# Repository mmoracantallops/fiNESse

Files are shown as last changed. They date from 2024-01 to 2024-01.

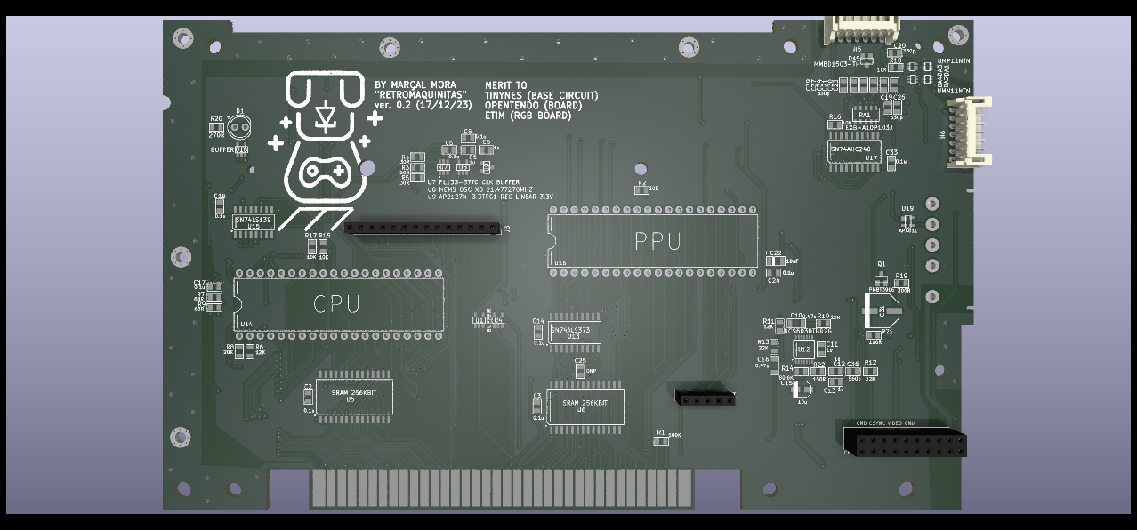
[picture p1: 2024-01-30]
MAIN_BOARD/FINESSE.png

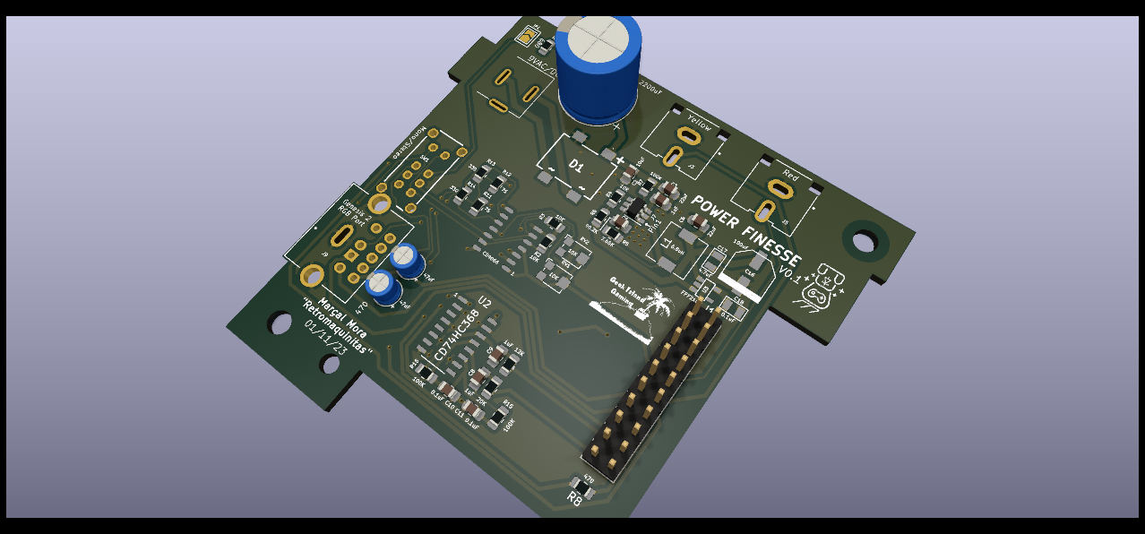
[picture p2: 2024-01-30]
POWER_BOARD/NES_POWER_FINESSE.png

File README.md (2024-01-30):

# fiNESse
Final Integrated NES Special Edition: Integration and adaptation of the best NES projects (TinyNES, NESRGB, OpenTendo and Power Module Redesign) in a single modern unit.

TinyNES: https://www.crowdsupply.com/tall-dog-electronics/tinynes

TinyNES: https://github.com/loglow/TinyNES

OpenTendo: https://github.com/Redherring32/OpenTendo

NESRGB: https://etim.net.au/nesrgb/

MerlinShaw's Power Modules: https://github.com/ShawMerlin/NES-Power-Module-Redesign

# Features (and limitations)
- Only NTSC (once you go 60Hz, there is no turning back), so RP2A03 / RP2C02, as the clock generator uses the NTSC frequency.
- Main board:
    - Similar features as the TinyNES project, although some features have been changed, simplified or adapted to my project (for instance, no USB or TRRS or clone compatibility here).
    - Modern ICs. All components are new and available.
    - Programmable clock generator (SIT2001BC-S2-33N-21.477270).
    - Reset supervisor (APX811).
    - Sockets to place the NESRGB Board wirelessly. Also taking external composite and audio from it.
    - Composite video generation and audio amplifier (internal).
    - Expansion audio connected.
- Power board:
    - Mini Din9 connector (MD/genesis 2 cable).
    - Rectifier (all polarities allowed).
    - Power load switch which provide full protection to systems and loads which may encounter large current conditions.
    - 5V step-down regulator.
    - Pseudo-stereo (separated channels CPU1 and CPU2). Mono is also mixed with both (adjustable on how much) so expansion audio is also mixed if desired.
    - Stereo audio is amplified with the same buffer as the original design.
    - Three-way switch (CVBS - mono, CSync - stereo, Csync - mono).
    - Much better routing and cleaner ground plane - although still not quite as good as Merlin Shaw's designs :)
    - Power LED (can be disabled or not populated).
    - 20 pin row to pass all the signals and ground connection between boards.
    - RCA connectors for composite video and audio.
 
# BOM
The current BOM is included here; I'm not sure whether I included everything but I did my best. If you notice some element is missing, please let me know. There are a few things that could be changed in the power board (e.g. the power regulator) for better availability, but I'll leave that for a future update. Of course, these are the components I had either because I based my design in the TinyNES or Merlin Shaw's or my own preferences and availability. Feel free to change anything if you feel like it.

# Pictures

## KiCAD
Gerbers are included. I might upload the full schematics and board once I find the time to clean them a little bit. These are the 3D models uploaded.
FINESSE
NES_POWER_FINESSE

## Main board

This is the produced (prototype) board:



Now, with the components soldered in place. Only the power/reset and controller connectors are sourced from another (preferably dead) NES. The 72 pin conector and load mechanism are also taken from another dead unit.



Notice there was a missing connection in the prototype with an easy fix; it is fixed in the uploaded version, though. The prototype also had a small issue with the blue power/reset connector; the tiny but long holes below caused an issue in manufacturing connecting Vcc and Ground planes. I moved the Vcc fill to prevent this from happening.



## Power board
And this is the companion power board, with direct RGB lines, etc.



And here with all the components soldered except the 20 pins that connect the board to the main board.


Finally, installed together with the main board and the soldered (tall - 21mm) pins:


## RGB Board
If the PPU is installed in the PPU slot and the switch set to internal video/audio, the console will output a (quite clean) composite video through the yellow RCA conector. But this is designed to be used with the NESRGB board, which fits perfectly and allows for a clean wireless installation and removal. In this picture, the pins are not soldered, but you get the idea. 



## Final Unit
Here is how it looks when finished. There is a potentiometer for the Expansion Audio and a Int/Ext Video/Audio on the main board and two potentiometers for the pseudo-stereo in the daughter power board.


## Extras: case

If you feel fancy, you can even use one of RetroGame Restore (https://retrogamerestore.com/) replacement shells and install both the MD2 type cable and the multiout one:



The metal sticker for the name/logo is from an etsy shop.


It works beautifully (at least in my humble opinion):


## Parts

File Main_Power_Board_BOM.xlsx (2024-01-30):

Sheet: Main_Board_BOM
Ref | Qty | Desc | Mfg | MPN
C1 C5 C11 C12 C13 | 5 | CAP CER 1UF 10V X7R 0805 | Samsung Electro-Mechanics | CL21B105KPFNNNE
C2 C3 C6 C7 C8 C9 C14 C17 C18 C24 C33 C38 | 12 | CAP CER 0.1UF 50V X7R 0805 | Samsung Electro-Mechanics | CL21B104KBCNNNC
C4 | 1 | CAP CER 10000PF 50V X7R 0805 | Samsung Electro-Mechanics | CL21B103KBANNNC
C10 C16 | 2 | CAP FILM 0.47UF 20% 16VDC 1206 | Panasonic Electronic Components | ECP-U1C474MA5
C15 | 1 | CAP ALUM 10UF 20% 16V SMD | Würth Elektronik | 865080340001
C19 C20 C21 C23 C26 C30 C34 C37 C39 | 9 | CAP CER 330PF 50V C0G/NPO 0805 | YAGEO | CC0805JRNPO9BN331
C22 | 1 | CAP TANT 10UF 10% 16V 1206 | KYOCERA AVX | TAJA106K016RNJ
C27 C28 C29 | 3 | CAP FILM 1UF 20% 16VDC 1210 | Panasonic Electronic Components | ECP-U1C105MA5
C31 | 1 | CAP ALUM 220UF 20% 10V SMD | Nichicon | UWX1A221MCL1GB
C32 | 1 | CAP ALUM 100UF 20% 10V SMD | Panasonic Electronic Components | EEE-HA1A101WP
C35 | 1 | CAP CER 560PF 50V C0G/NPO 0805 | YAGEO | CC0805JRNPO9BN561
C36 | 1 | CAP CER 4.7UF 16V X7R 0805 | Murata Electronics | GRM21BR71C475KE51L
DA1 DA3 | 2 | DIODE ARRAY GP 80V 100MA UMD6 | Rohm Semiconductor | UMP11NTN
DA2 DA4 | 2 | DIODE ARRAY GP 80V 100MA UMD6 | Rohm Semiconductor | UMN11NTN
DA5 | 1 | DIODE ARRAY GP 180V 200MA SOT23 | Micro Commercial Co | MMBD1503-TP
P1 | 1 | TRIM 100K OHM 0.5W GW TOP ADJ | Bourns Inc. | 3361P-1-104GLF
Q1 | 1 | TRANS PNP 40V 200MA TO236AB | Nexperia USA Inc. | PMBT3906,235
R1 | 1 | RES 100K OHM 1% 1/8W 0805 | Stackpole Electronics Inc | RMCF0805FT100K
R2 R15 R16 R17 R18 | 5 | RES 10K OHM 1% 1/8W 0805 | YAGEO | RC0805FR-0710KL
R3 R4 R5 | 3 | RES 30 OHM 1% 1/8W 0805 | YAGEO | RC0805FR-0730RL
R6 R11 | 2 | RES 12K OHM 0.5% 1/8W 0805 | Panasonic Electronic Components | ERA-6AED123V
R7 R9 | 2 | RES 68 OHM 1% 1/8W 0805 | YAGEO | RT0805FRE0768RL
R8 | 1 | RES 20K OHM 1% 1/4W 0805 | Stackpole Electronics Inc | RNCP0805FTD20K0
R10 R12 R13 | 3 | RES 22K OHM 1% 1/8W 0805 | YAGEO | RT0805FRE0722KL
R14 | 1 | RES 80.6K OHM 0.1% 1/8W 0805 | Panasonic Electronic Components | ERA-6AEB8062V
R19 | 1 | RES 300 OHM 1% 1/8W 0805 | YAGEO | RC0805FR-07300RL
R20 | 1 | RES 270 OHM 1% 1/8W 0805 | YAGEO | RC0805FR-07270RL
R21 | 1 | RES 110 OHM 5% 1/8W 0805 | Panasonic Electronic Components | ERJ-6GEYJ111V
R22 | 1 | RES 150 OHM 0.1% 1/8W 0805 | YAGEO | RT0805BRD07150RL
R23 R24 | 2 | RES 5.1K OHM 1% 1/8W 0805 | YAGEO | RC0805FR-075K1L
RA1 | 1 | RES ARRAY 8 RES 10K OHM 2512 | Panasonic Electronic Components | EXB-A10P103J
U1 U4 U18 | 3 | IC BUFFER INVERT 5.5V SOT23-5 | Texas Instruments | SN74LVC1G240DBVT
U5 U6 | 2 | IC SRAM 256KBIT PARALLEL 28SOP | ISSI, Integrated Silicon Solution Inc | IS62C256AL-45ULI-TR
U7 | 1 | IC CLK BUFFER 1:3 150MHZ 6SOT23 | Microchip Technology | PL133-37TC
U8 | 1 | IC MEMS OSC XO 21.477270MHZ SMD | SiTime | SIT2001BC-S2-33N-21.477270
U9 | 1 | IC REG LINEAR 3.3V 300MA SOT23 | Diodes Incorporated | AP2127N-3.3TRG1
U12 | 1 | IC LINE DRIVER 14TSSOP | onsemi | NCS603DTBR2G
U13 | 1 | IC LATCH TRANSP OCTAL D 20SO | Texas Instruments | SN74ALS373ANSR
U15 | 1 | IC DECODER/DEMUX 1X2:4 16SOIC | Texas Instruments | SN74LS139ADR
U17 | 1 | IC BUFFER INVERT 5.5V 20SO | Texas Instruments | SN74AHC240NSR
U19 | 1 | IC SUPERVISOR 1 CHANNEL SOT143 | Diodes Incorporated | APX811-46UG-7

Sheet: Power_Board_BOM
 |  |  | Comment
1 | C1 | 2200uF 25V
1 | C2 | 10nF
2 | C3, C6 | 22uf/25
1 | C4 | .1uF/25
1 | C5 | 1uF
2 | C8, C9 | 1uF
2 | C10, C11 | 0.1uF
2 | C12, C13 | 47 uF
1 | C16 | 100u
1 | C17 | 4.7u
1 | C18 | 0.1u
1 | D1 | D_Bridge_+-AA | HBS510-HF
1 | D2 | Power LED | 0805
1 | J1 | Board Connector | Double row male pin connector (21mm)
1 | J2 | 694106301002 | PJ-037A or similar
1 | J3 | Yellow RCJ- | RCJ-044
1 | J5 | Red RCJ-042 | RCJ-042
1 | J7 | Conn_01x06 | BL8033 Regulator
1 | J9 | MD-90SM | MD-90SM
1 | JP1 | SolderJumper_2_Open
1 | L1 | 6.8uH | LCSC C206253
1 | R1 | 680
2 | R2, R3 | 10K
1 | R4 | 10k
1 | R5 | 7.68k
1 | R6 | 40.2k
1 | R7 | 100K
1 | R8 | 470
1 | R9 | 20K
1 | R10 | 12K
2 | R11, R12 | 75
2 | R13, R14 | 330
2 | R15, R16 | 100K
2 | RV1, RV2 | R_20K | TC33X-2-203G
1 | SW1 | DP3T | EG2319
1 | U1 | CD4066BM96
1 | U2 | CD74HC368M
1 | U3 | FPF210X | FPF2107

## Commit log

2024-01-30 Create info in main board
2024-01-30 Create info in power board
